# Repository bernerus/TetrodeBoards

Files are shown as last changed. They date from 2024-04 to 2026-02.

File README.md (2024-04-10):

# TetrodeBoards
The Tetrode Boards by Ian White, GM3SEK. Redesigned with KiCad.

In 1998 Ian White, G3SEK, nowadays GM3SEK designed control and protection circuits for RF power amplifiers
that use tube tetrodes. These boards were sold for many years by the designer but were retired around 2017
and are no longer available.

The manuals are still available however, and that documantation is excellent. 

After my retirement as a system developer I found time to return to the VHF DXing that I used to do as a 
student in the late 1970's.
By then one of the things I built was a VHF power amplifier, described by Fred Merry, W2GN, which was used
even for some EME contacts until around 1987 when a storm took my antenna. Since then, the amplifier was
only used occasionally.

Now, 37 years later, the ham world has changed quite a lot. Nowadays computers make the waveforms and almost
every ham has a spectrum analyzer built into their radio. My signals from the old PA didn't look very good there.

Actually it is probaly at miracle that the PA and its power supply worked at all now. There were lots of electrolytic
capacitors in the power supply that were surplus already in the mid 1970's, and when I got reports on hum on my
signal, I checked these caps. I had only about 8 uF left and the G1 and G2 voltage varied too much to be happy with.

That's when I found out that these tetrode boards could help, but since the boards were no longer sold, I decided
to try to re-engineer them using KiCad. This time using methods available today. Thus this design uses SMD mounted
components and professionally produced boards. I have some boards left, so anyone who likes to try building on these
boards can have them for the expense of postage. Beware though that they have issues. Check the issues tab at GitHub first.

A crucial component in Ian's design is the 748 op amp. 
These are no longer manufactured, but they are available at eBay.
Luckily for me, I found a few 748 IC:s leftover from the happy '70s in my old junkbox. 

Christer Bernérus, SM6FBQ. 
JO67BQ 2024-04-04.

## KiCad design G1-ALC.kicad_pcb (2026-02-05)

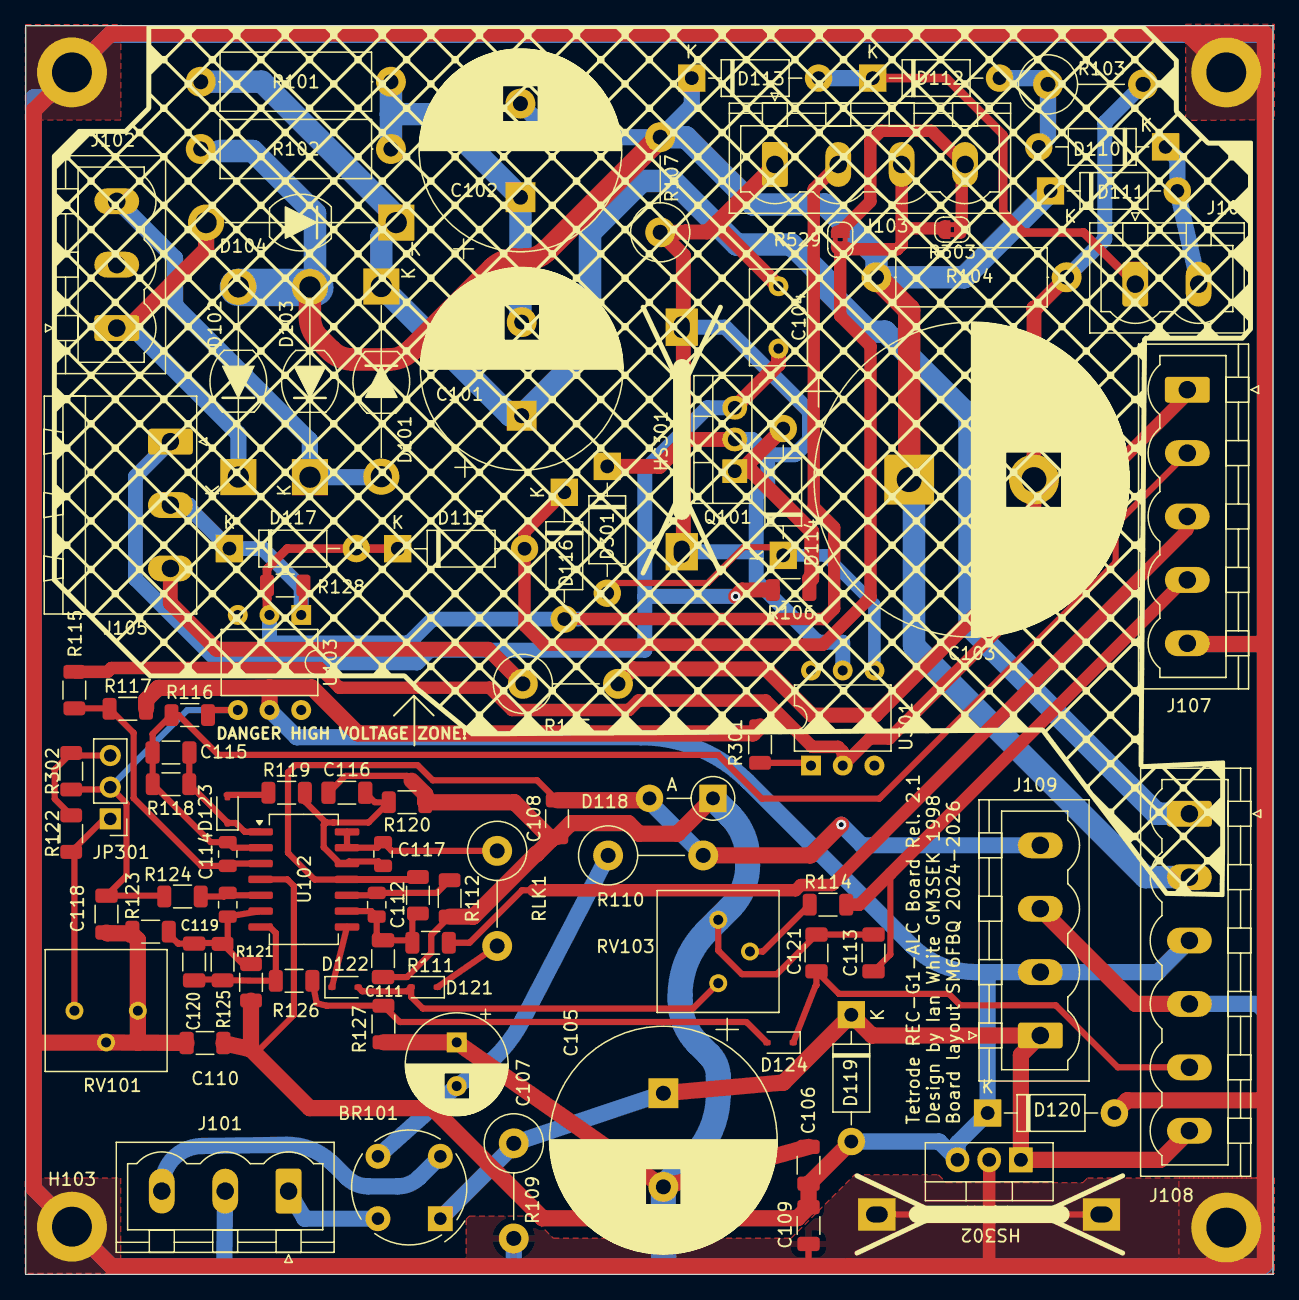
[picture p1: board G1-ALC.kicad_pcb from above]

Board: 2 copper layers, 100.0 x 100.1 mm, 96 parts (0 on the bottom side), 49 nets.

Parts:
BR101: 2W06; Diode_Bridge_Round_D9.0mm
C101, C102: 100u 350V; CP_Radial_D16.0mm_P7.50mm
C103: 220u 200V; CP_Radial_D25.0mm_P10.00mm_SnapIn
C104: 100n 100V; C_Disc_D7.5mm_W4.4mm_P5.00mm
C105: 4m7 35V; CP_Radial_D18.0mm_P7.50mm
C106, C108, C109, C110, C111, C113, C115, C118, C120, C121: 100n; C_1206_3216Metric
C107: 100u 35V; CP_Radial_D8.0mm_P3.50mm
C112, C114, C117, C119: 33p; C_0805_2012Metric
C116: 1u; C_1206_3216Metric
D101, D102, D103, D104: BY228; D_SOD-64_P15.24mm_big_holes_Horizontal
D110, D111, D112, D113, D115, D116, D117, D119, D120: 1N4007; D_DO-41_SOD81_P10.16mm_Horizontal
D114: BZX85C56; D_DO-41_SOD81_P10.16mm_Horizontal
D118: BZX55C12V; D_DO-41_SOD81_P5.08mm_Vertical_AnodeUp
D121, D122, D123, D124: 1N4148WS; D_SOD-323
D301: 1N5365 36V; D_DO-41_SOD81_P10.16mm_Horizontal
H101, H102, H103, H104: MountingHole_Pad; MountingHole_3.2mm_M3_DIN965_Pad
HS301, HS302: Heatsink_Pad_2Pin; 6025DG_Cooler
J101: Conn_01x03_Pin; PhoenixContact_MSTBVA_2,5_3-G-5,08_1x03_P5.08mm_Vertical
J102: 330VAC; PhoenixContact_MSTBVA_2,5_3-G-5,08_1x03_P5.08mm_Vertical
J103, J109: G1 conn.; PhoenixContact_MSTBVA_2,5_4-G-5,08_1x04_P5.08mm_Vertical
J104: 105VAC in; PhoenixContact_MSTBVA_2,5_2-G-5,08_1x02_P5.08mm_Vertical
J105: Conn_01x03_Pin; PhoenixContact_MSTBA_2,5_3-G-5,08_1x03_P5.08mm_Horizontal
J107: Conn_01x05_Pin; PhoenixContact_MSTBVA_2,5_5-G-5,08_1x05_P5.08mm_Vertical
J108: G2 Control board interconnect; PhoenixContact_MSTBVA_2,5_6-G-5,08_1x06_P5.08mm_Vertical
JP301: ALC tune; PinHeader_1x03_P2.54mm_Vertical
Q101: TIP122; TO-220-3_Vertical
R101, R102, R104: 100k 2W; R_Axial_DIN0414_L11.9mm_D4.5mm_P15.24mm_Horizontal
R103: 1k5 2W; R_Axial_DIN0414_L11.9mm_D4.5mm_P7.62mm_Vertical
R105: 3k3 2W; R_Axial_DIN0414_L11.9mm_D4.5mm_P7.62mm_Vertical
R106, R122: 470R; R_1206_3216Metric
R107, R109: 4k7 2W; R_Axial_DIN0414_L11.9mm_D4.5mm_P7.62mm_Vertical
R110: 470R 1W; R_Axial_DIN0414_L11.9mm_D4.5mm_P7.62mm_Vertical
R111, R112, R115, R116, R121, R124: 10k; R_1206_3216Metric
R113: 100k; R_1206_3216Metric
R114: 100R; R_1206_3216Metric
R117, R118, R125: 470k; R_1206_3216Metric
R119: 2k7; R_1206_3216Metric
R120: 1M; R_1206_3216Metric
R123, R128: 22k; R_1206_3216Metric
R126: 39k; R_1206_3216Metric
R127: 33k; R_1206_3216Metric
R301: 270R; R_1206_3216Metric
R302: 560R; R_1206_3216Metric
R303, R529: 0; SolderJumper-2_P1.3mm_Bridged2Bar_RoundedPad1.0x1.5mm
RLK1: 0R; R_Axial_DIN0414_L11.9mm_D4.5mm_P7.62mm_Vertical
RV101: 1k; Potentiometer_Bourns_3386P_Vertical
RV103: 10k; Potentiometer_Bourns_3386P_Vertical
U101: LM7812_TO220; TO-220-3_Vertical
U102: LM324; SO-14_5.3x10.2mm_P1.27mm
U103: MCT5211M; DIP-6_W7.62mm
U301: CNY17-4; DIP-6_W7.62mm

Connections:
+12V: C106.1, C109.1, C110.1, D119.2 (A), D120.1 (K), J108.3, J109.2, R117.2, R121.2, R301.1, U101.3 (VO), U102.4 (V+), U103.5
+24V Unreg: BR101.1 (+), C105.1, D119.1 (K), J108.6, J109.1, R109.1, U101.1 (VI)
-12V: C108.2, D118.2 (A), J109.4, R110.2, R113.1, U102.11 (V-)
/18 VAC +: BR101.4, J101.1
/18 VAC -: BR101.2, J101.3
/105 VAC +: D112.1 (K), D113.2 (A), J104.1
/105 VAC -: D110.1 (K), D111.2 (A), J104.2
/330VAC +: D102.1 (K), D104.2 (A), J102.1
/330VAC -: D101.2 (A), D103.1 (K), J102.3
/ALC: C113.1, J107.4, R114.2
/Cathode: C102.2, C103.1, D102.2 (A), D103.2 (A), D111.1 (K), D113.1 (K), J108.2, R102.2, R104.1, R107.2
/Class AB1_L: J107.1, R115.1, U301.2
/G1: J103.4, R303.1, R529.1
/G1 Switch: C104.1, D301.1 (K), HS301.1, HS301.2, J103.1, Q101.2 (C), R107.1, U301.5
/G1 meter +: D115.1 (K), D116.2 (A), D117.2 (A), J103.2, R128.1, U103.2
/G1 meter -: D115.2 (A), D116.1 (K), J103.3, R303.2, R529.2
/G1 trip: C121.2, D124.1 (K), J108.5
/G2 Unreg: C101.1, D101.1 (K), D104.1 (K), J108.1, R101.1
/Ig1: C114.2, C115.1, J107.2, R116.1, R118.1, U102.2 (-)
/Inhibit: J107.3, R111.1
/RV102 Cold: C104.2, J105.1, Q101.3 (E), R106.2
/RV102 Hot: J105.3, R105.1
/RV102 Mid: D117.1 (K), J105.2, R128.2, U103.1
GND: C105.2, C106.2, C107.1, C108.1, C109.2, C110.2, C111.2, C113.2, C116.1, C118.2, C121.1, D118.1 (K), D120.2 (A), H101.1, H102.1, H103.1, H104.1, HS302.1, HS302.2, J101.2, J107.5, J108.4, J109.3, R109.2, R112.2, R120.1, R123.1, R127.1, RV101.2, RV101.3, RV103.3, U101.2 (GND)
unnamed: BR101.3 (-), C107.2, R110.1
unnamed: C101.2, C102.1, R101.2, R102.1
unnamed: C103.2, R103.2, R104.2, R105.2
unnamed: C120.2, R125.2, R126.1, U102.7
unnamed: D110.2 (A), D112.2 (A), R103.1
unnamed: D114.2 (A), Q101.1 (B), R106.1
unnamed: D114.1 (K), D301.2 (A), U301.4
unnamed: D121.2 (A), D122.2 (A), RV103.1
unnamed: D121.1 (K), RLK1.2
unnamed: D122.1 (K), U102.8
unnamed: D123.2 (A), R119.1
unnamed: C115.2, D123.1 (K), R118.2, U102.1
unnamed: D124.2 (A), R126.2, R127.2
unnamed: JP301.1 (A), R122.2, RV101.1
unnamed: JP301.3 (B), R122.1, R302.2
unnamed: C118.1, JP301.2 (C), R116.2, R124.1, R302.1, U103.4
unnamed: R114.1, RV103.2
unnamed: R301.2, U301.1
unnamed: C114.1, R115.2, R117.1, U102.3 (+)
unnamed: C119.1, R124.2, U102.5 (+)
unnamed: C119.2, C120.1, R121.1, R123.2, R125.1, U102.6 (-)
unnamed: C112.1, R112.1, U102.10 (+)
unnamed: C111.1, C112.2, R111.2, R113.2, U102.9 (-)
unnamed: C116.2, C117.1, R119.2, R120.2, U102.12 (+)
unnamed: C117.2, RLK1.1, U102.13 (-), U102.14

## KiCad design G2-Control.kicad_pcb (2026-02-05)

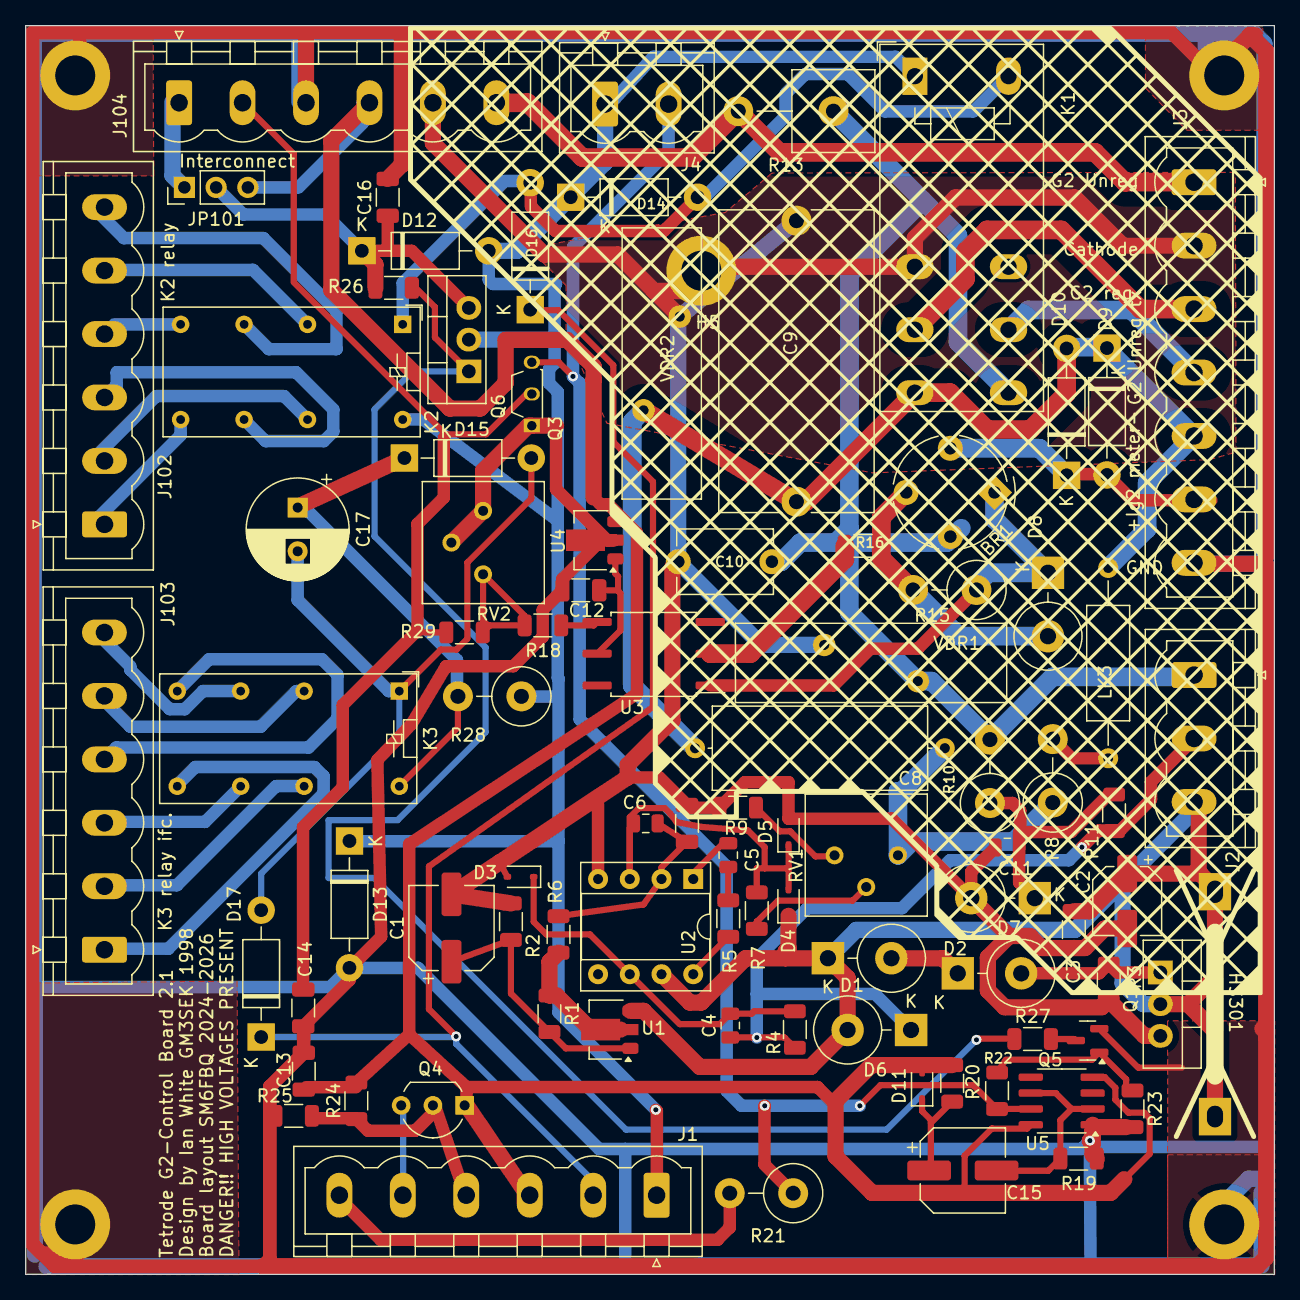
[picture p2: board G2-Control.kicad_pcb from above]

Board: 2 copper layers, 100.0 x 100.0 mm, 93 parts (0 on the bottom side), 61 nets.

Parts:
BR1: 2W06; Diode_Bridge_Round_D9.0mm
C1, C15: 100u 16V; CP_Elec_6.3x5.7
C2: 10u 50V; CP_Elec_5x5.4
C3, C7, C13, C14, C16: 100n; C_1206_3216Metric
C4: 10n; C_0805_2012Metric
C5, C6: 33p; C_0805_2012Metric
C8: 4n7 630V; C_Axial_L17.0mm_D6.5mm_P20.00mm_Horizontal
C9: 100n 1kV; C_Rect_L24.0mm_W12.2mm_P22.50mm_MKT
C10: 10n 1kV; C_Disc_D7.5mm_W5.0mm_P7.50mm
C11: 470n; C_0805_2012Metric
C12: 10u; C_1206_3216Metric
C17: 100u 50V*; CP_Radial_D8.0mm_P3.50mm
D1, D2: BZX55C15V; D_DO-201_P5.08mm_Vertical_KathodeUp
D3, D4, D5, D11: 1N4148WS; D_SOD-323
D6: BZX55C12V; D_DO-201_P5.08mm_Vertical_KathodeUp
D7: BZT03C82; D_DO-201_P5.08mm_Vertical_KathodeUp
D8: 1N5337B; D_DO-201_P5.08mm_Vertical_KathodeUp
D9, D10, D12, D13, D14, D15, D16, D17: 1N4007; D_DO-41_SOD81_P10.16mm_Horizontal
H1, H2, H3, H4, H5: MountingHole_Pad; MountingHole_3.2mm_M3_DIN965_Pad
HS301: Heatsink_Pad_2Pin; 6025DG_Cooler
J1, J102, J103: Conn_01x06_Pin; PhoenixContact_MSTBVA_2,5_6-G-5,08_1x06_P5.08mm_Vertical
J2: Q2_link; PhoenixContact_MSTBVA_2,5_3-G-5,08_1x03_P5.08mm_Vertical
J3: Conn_01x07_Pin; PhoenixContact_MSTBVA_2,5_7-G-5,08_1x07_P5.08mm_Vertical
J4: Conn_01x05_Pin; PhoenixContact_MSTBVA_2,5_2-G-5,08_1x02_P5.08mm_Vertical
J104: Board Interconnect; PhoenixContact_MSTBVA_2,5_6-G-5,08_1x06_P5.08mm_Vertical
JP101: Relay voltage; PinHeader_1x03_P2.54mm_Vertical
K1: Schrack RTE24024; Relay_DPDT_Schrack-RT2-FormC_RM5mm
K2, K3: AZ822-2C-24DSE; Relay_DPDT_Omron_G5V-2
LK3: Jumper_2_Bridged; R_Axial_DIN0309_L9.0mm_D3.2mm_P15.24mm_Horizontal
Q1: TIP122; TO-220-3_Vertical
Q3: 2N5061; TO-92S_Wide
Q4: 2N4403; TO-92_Inline_Wide
Q5: BC847; SOT-23
Q6: IRF9530N; TO-220-3_Vertical
R1: 270R; R_1206_3216Metric
R2: 4k7; R_1206_3216Metric
R3: 470R; R_1206_3216Metric
R4: 39k; R_1206_3216Metric
R5: 2k7; R_1206_3216Metric
R6, R7: 22k; R_1206_3216Metric
R8: 470k 1W; R_Axial_DIN0414_L11.9mm_D4.5mm_P5.08mm_Vertical
R9: 27k*; R_1206_3216Metric
R10: 150k 1W*; R_Axial_DIN0414_L11.9mm_D4.5mm_P5.08mm_Vertical
R11: 82k; R_1206_3216Metric
R13: 10k 2W*; R_Axial_Power_L20.0mm_W6.4mm_P7.62mm_Vertical
R15: 120R 1W*; R_Axial_DIN0414_L11.9mm_D4.5mm_P5.08mm_Vertical
R16: 820R*; R_1206_3216Metric
R18: 220R; R_1206_3216Metric
R19: 330k*; R_1206_3216Metric
R20: 100k; R_1206_3216Metric
R21: 470R 1W; R_Axial_DIN0414_L11.9mm_D4.5mm_P5.08mm_Vertical
R22, R23, R24, R25, R26, R27, R29: 10k; R_1206_3216Metric
R28: 680 1W*; R_Axial_DIN0414_L11.9mm_D4.5mm_P5.08mm_Vertical
RV1: 10k; Potentiometer_Bourns_3386P_Vertical
RV2: 500R; Potentiometer_Bourns_3386P_Vertical
U1: LM317L_SOT89; SOT-89-3
U2: uA748; DIP-8_W7.62mm_Socket
U3: 4N36; SOP-6_6.62x6.62mm_P2.54mm
U4: 78L05; SOT-89-3
U5: LMC555CMX; SOIC-8_3.9x4.9mm_P1.27mm
VDR1, VDR2: V320LA40B*; RV_Disc_D21.5mm_W6.1mm_P7.5mm

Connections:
+5V: C12.1, U3.5, U4.1 (OUT)
+12V: C13.1, D11.2 (A), J1.3, J104.4, JP101.3 (B), Q4.1 (E), R20.2, R24.2, U4.3 (IN), U5.4 (R), U5.8 (VCC)
/24V Unreg: J104.1, JP101.1 (A)
/+30V rail: C2.1, C3.1, D1.1 (K), D4.1 (K), D6.2 (A), HS301.1, HS301.2, J2.3, Q1.2 (C), U1.3 (VI), U2.7 (V+)
/+Ig2: BR1.2, D9.2 (A), D10.1 (K), J3.6
/-Ig2: C8.2, C9.1, D9.1 (K), D10.2 (A), J3.5, K1.14, LK3.2 (B), VDR2.1
/AUX_TRIP_L: J4.2, Q3.3 (A), R21.1, R22.1, U5.7 (DIS)
/Alarm LED +: J1.5, Q4.3 (C)
/Alarm LED -: J1.6, R21.2
/CATHODE: C1.2, C2.2, C3.2, C7.2, C9.2, C10.2, C11.2, D3.2 (A), D5.2 (A), D7.2 (A), H5.1, J3.2, J104.5, K1.12, Q1.3 (E), R2.1, R3.1, R9.1, U2.4 (V-), VDR1.2, VDR2.2
/G1 trip: C14.1, J104.2, Q3.2 (G), R29.2
/G2 UNREG TX: J3.4, K1.21
/G2 Unreg: J3.1, J104.6, R13.2
/G2 reg: J3.3, K1.11
/HV Enable: D12.2 (A), D13.1 (K), D14.1 (K), J1.1, J4.1, K1.A1, K2.16, Q6.2 (D), R28.1
/K2B_NC: J102.6, K2.6
/K2B_NO: J102.4, K2.8
/K2B_com: J102.5, K2.4
/K2C_NC: J102.3, K2.11
/K2C_NO: J102.1, K2.9
/K2C_com: J102.2, K2.13
/K3B_NC: J103.6, K3.6
/K3B_NO: J103.4, K3.8
/K3B_com: J103.5, K3.4
/K3C_NC: J103.3, K3.11
/K3C_NO: J103.1, K3.9
/K3C_com: J103.2, K3.13
/PTT_L: D16.1 (K), D17.1 (K), J1.2
/Q2G: C4.1, D6.1 (K), J2.2, R4.2, R11.1
/R12: BR1.4, C10.1, J2.1, K1.24, R10.2, R13.1, VDR1.1
/Reset -: J1.4, Q4.2 (B), R24.1, R25.2
GND: C12.2, C13.2, C14.2, C16.2, D13.2 (A), H1.1, H2.1, H3.1, H4.1, J3.7, J104.3, Q3.1 (K), Q5.2 (E), R19.2, R23.2, R25.1, RV2.1, RV2.2, U4.2 (GND), U5.1 (GND)
unnamed: BR1.1 (+), D8.1 (K), R15.1, U3.1
unnamed: BR1.3 (-), D8.2 (A), R15.2, R16.2
unnamed: C5.1, R5.1
unnamed: C5.2, U2.1 (NULL)
unnamed: C8.1, R8.1, RV1.3
unnamed: D1.2 (A), D2.1 (K)
unnamed: D2.2 (A), Q1.1 (B), R3.2
unnamed: C4.2, D3.1 (K), R4.1, U2.6
unnamed: C6.1, D4.2 (A), D5.1 (K), R7.2, U2.3 (+)
unnamed: C11.1, D7.1 (K), R10.1, R11.2
unnamed: C15.1, D11.1 (K), R20.1
unnamed: C16.1, D12.1 (K), JP101.2 (C), Q6.3 (S), R26.1
unnamed: D14.2 (A), D16.2 (A), K1.A2, K2.1
unnamed: C17.2, D15.2 (A), D17.2 (A), K3.1
unnamed: C17.1, D15.1 (K), K3.16, R28.2
unnamed: LK3.1 (A), R8.2
unnamed: Q5.1 (B), R22.2, R23.1
unnamed: Q5.3 (C), R27.2
unnamed: Q6.1 (G), R26.2, R27.1
unnamed: R7.1, RV1.2
unnamed: R9.2, RV1.1
unnamed: R16.1, U3.2
unnamed: R18.1, R29.1, RV2.3
unnamed: R18.2, U3.4
unnamed: C1.1, R1.2, R2.2, U1.1 (ADJ)
unnamed: R1.1, R6.1, U1.2 (VO)
unnamed: C6.2, C7.1, R6.2, U2.2 (-)
unnamed: R5.2, U2.8 (FC)
unnamed: C15.2, R19.1, U5.2 (TR), U5.6 (THR)

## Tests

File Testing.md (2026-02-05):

# Testing and initial power up.

These are the testing steps I went through when powering up the boards the very first time.
If any test failed, I went back, documented the issue, produced a workaround or a fix and
updated the design to make the next release better.

## Low voltage DC power up.

### Transformer checks

In the following, I used two transformers, one for the low voltages and one for the higher voltages.
Hence, I'm talking about different transformers. If you have only one, after the identification and testing, be sure to keep the
high voltage windings isolated until they are actually being used.

#### Primary connection

Measure the primary winding. There may be many connections.
Find the pair of connections that have the largest resistance.
Connect these, in a safe way, to the mains voltage. You should hear a very soft hum
from the transformer. If it makes more noise that a soft hum, you might have connected
to the wrong winding or a pair of connections to the primary winding that was not designed
for your mains voltage.

Now let the transformer run on mains voltage without connecting anything to the secondary winding(s).
Observe it for 10 minutes, then disconnect it from mains, and feel it with your hands. It should not feel warm anywhere.
If it gets noisy, oe warm, or if you see smoke or you feel any smell from it, disconnect immediately. The primary test has failed.

#### Secondary winding check.

Now turn to the secondary winding. It should deliver at least 2x16V with a mid tap.
Identify the mid tap by measuring the voltage between the different connections. Find one pair that gives 32-48 Volts. These are
the outer connections. The mid tap is the third one. Check that the voltage between the mid tap and the outer connections is between
16 avd 19 V and absolutely no more than 24V. When done, disconnect tre transformer from the mains.

### G1-ALC Low voltage check

Connect the secondary winding connections to J101 of the G!-ALC board.with the mid tap
to the middle pole of J101. Turn the transformer on.

Check that the DC voltage between ground and pin 6 of J108 (closest to the corner) is 22-27V
Check that the DC voltage between ground and pin 3 of J108 and pin 2 of J109 is 11.8-12.3V
Check that the DC voltage between ground and pin 4 of J109 is about -12V.

Let the voltage be on for a few minutes and check that nothing is getting warm.

### G2-Control low voltage check

Turn off the transformer.

Make connections between J108 on the G1-ALC board to J104.
The pin order is order same on both boards, but mirrored,  so you could use a flat band of wires.

Verify the connection between J108 on the G1-ALC board to J104 by measuring the resistance from, JP101, pin closest to the corner on the G2 board,
to J108 pin 6, (closest to the corner) i.e. the middle of the board edge. It should be 0-0.2 ohms.

Unplug any jumper on JP101

Turn the transformer on again.
Check that the DC voltage on the pin closest to the corner of J104 is 22-27V
Check that the DC voltage on the 4:th pin from the corner of J104 is 11.8-12.3V
Check that the DC voltage on pin 1 of U4 is 5V.

Turn the transformer off

Re-plug any unplugged jumper on JP101

### G2-Control G2 rectifier low voltage check

Connect the low voltage transformer secondary to J102 on the G1-ALC board instead of J101.
Turn the transformer on

Check the DC voltage between CATHODE and G2-unreg pins of J108.
(These are the two pins of J108 closest to J104) You should see about 44-52 Volts, depending on the transformer.
Note that this is just a check using low voltages, in the final setup the voltage should be considerablu higher.

Turn the transformer off

## G1 voltage power up

### Transformer check

Apply mains power to the primary winding. Measure the voltages on the secondary windings,
Find out which winding gives about 100 VAC, and which gives more than 300VAC.
Disconnect the transformer from mains.

### Check voltages of the G1 section

Connect the low voltage transformer secondary to J101 on the G1-ALC board. J102 should be unconneced.
Connect the secondary 100 VAC winding to J104. Leave the 300VAC winding unconnected and isolated.
Smoke test. If something smells warm or smoke erupts, turn off both transformers immediately

#### Wire up a PTT button.
Connect a PTT button between J1 pin2 (PTT_L) and J3 pin 7 (GNDPWR) On the G2-control board.

#### Configure for G1 switching

If R107 is a resistor and not a link:
Connect a link between J102 pin 5 and J103 pin 5 on the G2-control board.
Connect a wire between J103 pin 4 and J3 pin 4 on the G2-control board. (CATHODE)
Connect a wire between J102 pin 4 on the G2-control and J103 pin 1 (G1 Switch) on the G1-ALC board.
Apply mains power to the low voltage transformer
Check with an ohmmeter that there is no connection between J103 pin 1 (G1 Switch) on the G1-ALC board
and J3 pin 4 on the G2-control board. When pushing the PTT switch, the relays should click and the
ohmmeter should read near 0 ohms. 

Release the button and the connection should disappear.

Disconnect mains power from the low voltage transformer

#### Wire up a switch for Class select
Get an SPST swich. Set the switch to open.
On the G1-ALC board, Connect it between J107 pin 1 (CLASS AB1_L, On version 2.0.0 boards erroneously marked G2 Unreg) 
and 5 (GND, On 2.0.0 boards erroneously marked G1 current trip).

#### Test G1 output voltages

Apply power to the low voltage transformer.

Connect both transformers to mains voltage.
Beware, there are now lethal voltages available on the boards.
Check that the DC voltage on the 4:th pin from the corner of J104 to ground is 11.8-12.3V
Check the G1 out voltage against the CATHODE rail (J108 pin 2), should be less than -100V.
Press the PTT button. The voltage should rise to about -93 to -92 Volts depending on the position of RV102.
Release the button.

Flip the SPST switch to the ON (Class AB1) position.
The voltage should be between -84 to -81V depending on the position of RV102
With the PTT button pressed, the voltage should rise to about between -50 to -56V V
Check that there is about 12V on J107 pin 1 against ground.

Disconnect mains power from the transformers

## G2 voltage check and adjustment

##### Check 30V Rail

Now, with the transformers off, connect the 100 VAC winding ( NO, not the 330V yet) to J102 on the G1-ALC board.
Connect the voltmeter between pin 4 and 7 of yet empty socket of U2. Positive on pin 7.
Turn on the transformers. The voltmeter should show +30V approximately. If not, fix before continuing. The 748 is precious!!
Turn the transformers off again.

##### Install the 748

Now it's time to put in the 748 in its socket. IMPORTANT! Do not continue without it or you will burn R13 due to VDR1 clamping the overvoltage produced without the 748 regulating it down below 400V.
Observe the polarity of the 748.

##### Connect the 330 volt winding

**WARNING EVEN MORE LETHAL VOLTAGES WILL BE PRESENT DURING THESE TESTS**

Disconnect the 100V Winding from J102 and put it back into J101.
Connect the 330V winding to J102 instead.

##### Test and measure the unregulated G2 voltage

Connect the voltmeter negative end to the CATHODE rail (J108-2 on G1 board)
Connect the voltmeter positive end to the G2-UNREG output (J108-1 on the G1 board)
Turn the transformer on briefly, the voltmeter should show between 350 to 400V.
If voltages seems OK, turn on for 10 seconds and then off.
Look and smell for smoke and heat building up. DO NOT TOUCH ANYTHING until the voltmeter goes below 30V.

Turn the transformers off.

##### Test the warm up timing

Wait for about 10 minutes before proceeding to allow the warmup timing capacitor to leed out all its charge. Get a stopwatch ready while waiting.
Turn the transformers again and start the stopwatch. The LED should be fully lit.
After about 2 or 3 minutes the LED should go almost off. Then stop the watch.
Check the required warmup time needed for your tube(s). You may want to adjust the value of R20 to get the desired time.
Remember that each time you thurn the transformer on, you will have to wait this time before trying to enable the G2 voltage.

##### Measure and adjust the G2 regulated voltage output

Now move the positive probe to the G2 Reg output (J3 pin 3)
Adjust RV102 to its middle position.
Turn the transformers on again.
Voltmeter should show 0 V because the relay connects to the CATHODE rail.
Push the PTT Button, the relays should click and the voltmeter should show over 300V.
Adjust RV101 while pushing the PTT switch until the voltmeter shows 350V (For 4CX250B)
Release the PTT switch and turn the transformers off.

##### Check waveform of G2

Connect an oscilloscope in parallel to the voltmeter. Use a 10x probe. Check that the waveform when pushing the PTT button
is absolutely flat. If not, the transformer may need more turns of wire for the G2 winding.

##### Adjust the G2 trip current.

Turn RV2 fully clockwise.
Compute what resistance is needed to load the trip current needed. I needed to load 40 mA and at 350V I needed a resistance of 8750 ohms at 14W.
Connect the load resistance between the G2 output pin and the cathode pin.
Connect the voltmeter to measure the current through the load resistance and fine adjust the resistance,
while pressing the PTT button until the current is at the computed trip current (40 mA in my case)
When you have the precise load resistance needed,
push the PTT button and very slowly turn RV2 counterclockwise until the LED lights up and the relays drop.
Press the reset button and the LED should go dark again.
disconnect the meter and leave the load current path open, Push the PTT button again and the LED should stay dark.

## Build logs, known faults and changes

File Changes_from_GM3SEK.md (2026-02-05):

I have made a few changes from Ian's original design.

# G2 rectifier

The original schematic shows four 1N4007 forming a rectifier bridge.
However, the original board layout shows that each leg of the
rectifier is supposed to use two 1N4007 in series.

Maybe things have changes the last 30 years, but then the usual way of
extending the voltage handling capability for a diode was to
put diodes in series and have bleeder resistances of equal values
parallelling the diodes to make sure that they split the back voltages
in equal parts. Also each diode should have a capacitor across to protect against
voltage surges. I couldn't see any place for resistors or capacitors on the photos
I have seen on the internet, I decided instead to use another diode, the BY220 which is
good for 3 A and 1200V. These are also avalanche diodes which means that they can
be put in series without any extra components. If you need more than one in series
for higher voltage, put one in each hole vertically and tie them together on top.
Dont forget to change the filter caps in that case.

# 24V Relays

I happened to have five PCB relays **with another pinout** than the ones Ian used, and they were
for 24V. I  changed the circuit to allow to feed unregulated 24V to the relays instead of 12V.
There is a jumper on the G2 board to select this.
This means two things:

1. Ian's description for wiring for G1 switching is not correct using my boards. The relay pinout differs.
2. The K3 relay has a capacitor and a series resistor to make it slow. From the original documentation,
   I reverse engineered the time-on and time-off delay to be ~330 mS and ~600 mS respectively.
   If another relay is used than the relay specified by Ian, the component values for R29 and C17
   will most likely to be recalculated. I used a 24V relay that needed >14V to turn on and <10V to turn off,
   and the coil resistance measured to 2900 ohms. Feeding this with 24V, I got 1800 ohms for R28 and 330 uF 25V
   for C17 to get about the same timing.

# Connectors

I like to be able to easily take out boards for inspection, repair or testing new ideas.
All connections have been taken to the edge of the board, or at least close to the edge.
There is space for Phoenix PCB connectors with 5.08 mm spacing.
There are matching female screw connectors for these and they are certified up to 500V.
Unfortunately they are a bit pricey.

# SMD components

I wanted to make a professional PCB. I have previously ordered PCB's from Elecrow who offer
PCBs for only $1 for 5 boards if the size is max 100x100 mm, so I wanted to keep the size down.
That's why I decided to use SMD components where possible. Mounting them may feel as a
challenge, but I also ordered a stencil for each board cost me another $10 but worth it.
The challenge is mostly to keep track on all components and putting them in place on the
solder paste. A hot air gun and the solder mask together with the surface tension of liquid
does the final adjustment.
The boards are two layer, plated through holes, tinned copper, solder mask and silkscreen print on both sides.
When ordering from Elecrow you always get 5 boards, but it is not uncommon that you get more, so I
have 10 empty boards left for anyone interested. I might lend you the stencils.

# Class C

Since '98 ham radio has evolved. Nowadays there is a lot of machine generated modes, most notably FT8.
Many of these modes employ a constant amplitude, this means that PA's in Class C are interesting again.
As an experiment I included some circuitry to make it possible to switch the bias voltage
between 2 different values. This circuit uses an optocoupler to short-circuit one zener diode
of two that makes up the bias reference.

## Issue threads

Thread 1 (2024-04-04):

Missing traces on the G1-ALC board

bernerus, 2024-04-04:
There are two missing traces on the G1-ALC board.
This was due to me not running the electrical design checker on the schematic and a grid mismatch.

The negative ends of C102 and R102 are not connected. They should both be connected to the CATHODE rail.

As for the capacitor, I just bent the negative lead towards the cathode of D113 and soldered it there on the rear side of the board.

As for R102 I bent the unconnected lead, the one closest to J102,  onto the anode end of D103 snd soldered it there, also on the rear side.

See also:
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

bernerus, 2024-04-13:
The missing traces has been added in release 2.0.0

Closed 2024-04-07.

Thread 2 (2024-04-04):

Too small holes for the BY228 diodes on the G1-ALC board.

bernerus, 2024-04-04:
To save space I replaced the double 1N4007 diodes on Ian's boards with
the more sturdy avalanche diodes BY228 which is good for 1200V and 3A.

However these diodes are so sturdy that they come
with 1.35 mm leads. I knew this but somehow in the process, the change in hole size got lost,
so to be able to fit the BY228 diodes, I first cut the leads to the approximate needed length.
Then mounted each end in a drill and while slowly turning the diode with the drill
I used a Dremel round sanding band at medium speed to sand down the other
end lead diameter to about 1mm (or until fitting the hole) for a length of approximately 3 mm.
This reveals its copper core but that only matters until it is soldered in place.

bernerus, 2024-04-13:
Board release 2.0.0 has larger holes.

Closed 2024-04-07.

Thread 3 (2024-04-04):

Connectors turned the wrong way

bernerus, 2024-04-04:
The silkscreen graphics in many places show the curly end turned outwards.
Don't mount them like this, turn the curly end inwards, otherwise the screws
will be turned inwards making it harder to measure voltages on the screws.

The silkscreen text showing what signal is connected to each pin still applies,
but pin numbering does not.

This issue applies to both boards.

The attached picture shows a screw connector inserted in a socket having the curls inwards.
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

bernerus, 2024-04-13:
The board release 2.0.0 has the graphics turned the right way. Note that pin numbering may be changed from r1.0.0

Closed 2024-04-07.

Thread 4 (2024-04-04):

G1-ALC board. Heat sink too close to capacitor

bernerus, 2024-04-04:
The heat sink that is cooling Q101 is too close to capacitor C101.
There is room enough for the heat sink itself but not really for the screw
that bonds to the transistor.
This causes the heatsink to lean over to C103 which doesn't look nice,
and the only way to mount the heatsink is to first screw Q101 together with
the heat sink and then solder the transistor, or alternatively to mount
C103 after mounting the heat sink.

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

bernerus, 2024-04-13:
Board release 2.0.0 has more space for the heat sink and also copper on top to facilitate soldering of the heat sink onto the board.

Closed 2024-04-07.

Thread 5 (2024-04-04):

G2-Control board:  U1 connected backwards

bernerus, 2024-04-04:
This is by far the worst issue. The LM317 voltage stabilizer U1 was turned the wrong way on the schematic compared to Ian's original.  Usually signals go from left to right in a schematic, and that's what I assumed, however in this case VIN is to the right
and VOUT to the left.
The electrical rules checker of course warned about this but I didn't run it. :-(

The consequence is that this error has of course migrated to the physical board, and U1 is here a SMD component so the fix requires surgery that connect the pads of R1 and R2 being closest to each other to be isolated from U1 pin 3 and instead
be connected ti U1 pin 2. Likewise the 30V rail that starts at U2 pin 7 snd that makes a clockwise loop around R4 and must be isolated from U1 pin 2 and instead be connected to pin 3.

I made a cut in the 30V rail track about 3 mm from U1 pin 2, and scraped the copper clean on about 1mm along the other side of the cut, i.e. the side still connected to U2 pin 7. Tinned the free copper and soldered a tinned piece of cutaway resistor lead between U1 pin 3 and the tinned copper.

On the other side of U1 I cut  track leading to pin 3 immediately at the edge of U1 and soldered a cutaway resistor lead between  the pad of R1 that is connected to R2, to the rear side of U1 pin 2.

See this picture.
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

bernerus, 2024-04-13:
The board release 2.0.0 has this issue fixed.

Closed 2024-04-07.

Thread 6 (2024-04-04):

G2-Control board: Awkwardly turned Q1

bernerus, 2024-04-04:
Q1 on the G2-Control board is turned such that the heat sink is facing to the inward of the board. Then it comes very close to
the capacitor C2. It should be turned the other way round so that the heat sink could be soldered directly to the grounded edge of the board, provided that Q1 is mounted isolated from the heat sink.

bernerus, 2024-04-13:
Board release 2.0.0 has Q1 the other way around.

Closed 2024-04-07.

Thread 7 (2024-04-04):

D6 can reside on the G2-Control board

bernerus, 2024-04-04:
The zener diode D6 was excluded from the G2-control board because it was drawn in the breakout box together with Q2 and R12.
However both nets it is connecting to are also available on the board, thus it can be placed there somewhere, simplifying the
off-board circuitry.

bernerus, 2024-04-13:
Woarkaround for boards Release 1.0.0 is tho mount the diode with the cathode end onto thr outer enf of R4 and the anode end onto the cathode end of D1. The first point should be connected to the middle pin of J2, and the second to the pin closest to Q1 of J2
on the original first batch of boards. Of course it can be mounted on the backside of the board directly on the J2 pins, but maybe you want the back side clean of components.

bernerus, 2024-04-13:
Board release 2.0.0 has D6 incorporated.

Closed 2024-04-07.

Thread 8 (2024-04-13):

J107 and J108 should change places on the G1-ALC Board

bernerus, 2024-04-13:
J108 is the interconnect receptacle for the G2-controö board. It would look better
if J108 changed place with J107 because then the interconnect would line up
with the interconnect on the G2-Control board,

bernerus, 2024-04-13:
This was easier than I thought. However it expanded the high voltage zone, but the new layout has that zone clearly printed.

bernerus, 2024-04-13:
The board release 2.0.0 has the connectors swapped. This changes the external interface, which requires a major release numbewr bump.

Closed 2024-04-13.

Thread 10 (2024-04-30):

R26 must connect to the source of Q6.

bernerus, 2024-04-30:
In the original schematic, I connected the hot end of R26 to +12V. This does not work when using 24V feed to the relays.
To make it work, the hot end of R26 must be connected directly to the source of Q6.

bernerus, 2024-05-05:
The schematic and the PCB has been changed accordingly.

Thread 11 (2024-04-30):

Q4 turned backwards

bernerus, 2024-04-30:
The silkscreen print turns Q4 backwards. This was actually caused by selecting wrong schematic symbol which numbered the pins in the wrong direction for the 2N4403. The workaround for the initial board is just to mount Q4 the other way round, i.e. against
what the silkscreen print show.

Closed 2024-05-05.

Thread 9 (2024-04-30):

Q6 connected backwards.

bernerus, 2024-04-30:
The MOSFET Q6 that controls the T/R Relay was originally turned upside down in the schematic.
This caused the Drain and Source pins to be interchanged on the original PCB.
Due to the pinout of the IRF9530 this cannot be fixed by mounting the transistor reversed.

bernerus, 2024-05-05:
I did work around this. It was a bit tricky.
There are two trace cuts to make:
1: On the reverse side, cut the connection to the Q6 pin closest to J104 right where the trace leaves the pin.
2. On the top side, cut the trace leading from the cathode end of D12 to the middle pin of Q6.

Then there are two patches to add:
A: On the reverse side, connect a wire from the cathode pin of D12 to the Q6 pin closest to J104.
B: Also on the reverse side, connect a wire fron the anode pin of D12 to the middle pin of Q6.

On the first picture, there is a red wire leading to the cathode of D12. This wire does not have anything to do with this issue.
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
[](url)
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

bernerus, 2024-05-05:
Second picture shows the patches on the reverse side.

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

bernerus, 2024-05-05:
The symbol has been turned correctly in the schematic and the PCB traces have been updated.

Closed 2024-05-05.

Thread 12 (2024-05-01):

Warmup time and R20

bernerus, 2024-05-01:
The warmup time with the default seems to be 2 minutes.
That's a long time and lot all tubes need to have that long time to warm up.
To shorten the warmup time, decrease the value of R20.

bernerus, 2024-05-05:
Changed the value of R20 from 100k to 100k* to mark as something that might need adjustment. Different tubes needs different warmup time.

Closed 2024-05-05.

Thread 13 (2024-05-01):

G2 trip current too high

bernerus, 2024-05-01:
I wanted the G2 trip current to be 30 mA. That could not be achieved, It turned out that the value of R16 (1k5) was too high and caused the optocoupler to only deliver a few milliamps at 30 mA IG2. Changing R15 from 82R to 120R did not help.
I put another 1k5 in parallell which made it possible to set the 30 mA limit somewhere in the middle range of  RV2. In the next version I will change R16 to 820R.

bernerus, 2024-05-05:
R16 changed to 820R* (* to mark as something that might need adjustments) in the schematic. No change to the PCB.

Closed 2024-05-05.

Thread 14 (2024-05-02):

Wrong value for R128

bernerus, 2024-05-02:
The value for R128 should be 22k, not 1k5 as it is in the initial release.

bernerus, 2024-05-05:
My workaround was to desolder R128 and soldering in a THT resistor directly between pins 1 and 2 on U103.

The value of R128 has been updated in the schematic. There is no change to the PCB. Just use the correct value.

Closed 2024-05-05.

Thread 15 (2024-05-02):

R123  Missing

bernerus, 2024-05-02:
R123 is missing from the initial schematic. Consequently also on the initial PCB.

bernerus, 2024-05-05:
With the initial board, the workaround is to add a THT resistor according to attached picture. I did not find a 22k resistor small enough. The resistor I used is 23k.
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

bernerus, 2024-05-05:
R123 has been added to the schematic and the PCB in version 2.0.0.

Closed 2024-05-05.

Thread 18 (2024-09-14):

Pads for R106 on the G1-ALC board is  missing

bernerus, 2024-09-14:
The soldering pads for R106, 470 Ohms, is missing.
The resistor can however easily be soldered on the backside of the bard between Q101-3 and D114-2.

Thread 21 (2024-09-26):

100k too high a value for R126

bernerus, 2024-09-26:
The SCR did not react to G1 current too high. I could see that U102 was delivering +12V, but still
the SCR did not fire. Measuring the voltage at the cathode of D124 showed only 0.719V. The SCR needs 0.8 V to trigger.
Experimentally I found that 56k worked in version  1.0, but in version 2, I needed to go to 39k to establish good functionality.
There seems to be quite some spreading of component values. Maybe we need even lower values.

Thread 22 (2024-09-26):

ALC troubleshooting

bernerus, 2024-09-26:
The manual from GM3SEK states in chapter 9.5 step 8 that it might be necessary to either
short-circuit R122 (under the board) or change its value to 1k.
This procedure becomes quite awkward to do as these components are here surface mounted.
For version 2.1 I added a 560 ohm resistor in series with R122 and a 3 way jumper to be able to achieve
all 3 options here. See the notes page of the schematic.

Disbarred, 2025-06-10:
Happy to find this group.  Been tinkering with my 4cx30a HF Tetrode Board project since 2020.
How can I learn about the newer SMT boards?
Neil, n2eye, NY City

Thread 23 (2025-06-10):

Interested in new version of Tetrode Boards w/ SMT components

Disbarred, 2025-06-10:
I have been building (seems to never stop, lol) my Tetrode Boards HF amp since 2020  (2x 4cx300a).  I certainly want to keep this project alive and available for the Amateur Radio community.  Where can I learn more about and/or obtain a set of the newer boards?
Neil, NY City, n2eye
antclacorp@aol.,com

bernerus, 2025-06-12:
Hello Neil.

Well, I haven't published anything about this yet because I wanted to complete my rebuild of the PA power supply which contains the tetrode boards. While not fully done that – I want to integrate some remote control and telemetry – I can now see that the tetrode boards at least guards against G2 current runaway, but maybe it is too good. One thing that seems to have been forgotten by G3SEK is the bleed current caused by resistors at the tube sockets. This current is constant and positive, and it does not go into the screen grids of the tube, but the tetrode boards still sense it and maybe triggers the safety mechanism too early. I will think through this during the summer. Another thing is the Class C option  that I built into the new boards. As it it implemented now it only affects the G1 bias, and that seems to work. However in the class C case more G1 current should probably be allowed. This is something that also needs to be tested, as well as whether the G! voltage regulation works as it should.

Yet another thing is the use of the 748. These chips hasn't been produced for decades. I happened to have just a few lying around from the 1970's so that's what I used. They can be found on eBay though, but if this project is going to survive, maybe another circuit needs to be found.

I'll have to check in the latest version of my design, the version I have tested. The kiCad sources and gerbers will be updated here at GitHub.

I used the Chinese company Elecrow to produce the boards. They make them in small quantities  for 1 USD if the size is max 100x100 mm.
A stencil for the SMD pads cost 5 USD. Freight to Sweden is about 8 USD, and no tariffs as far as I can see.

Disbarred, 2025-06-18:
Thank you. n2eye

Sent from the all new AOL app for iOS

On Thursday, June 12, 2025, 6:38 AM, Christer Bernérus ***@***.***> wrote:

bernerus left a comment (bernerus/TetrodeBoards#23)
Hello Neil.

Well, I haven't published anything about this yet because I wanted to complete my rebuild of the PA power supply which contains the tetrode boards. While not fully done that – I want to integrate some remote control and telemetry – I can now see that the tetrode boards at least guards against G2 current runaway, but maybe it is too good. One thing that seems to have been forgotten by G3SEK is the bleed current caused by resistors at the tube sockets. This current is constant and positive, and it does not go into the screen grids of the tube, but the tetrode boards still sense it and maybe triggers the safety mechanism too early. I will think through this during the summer. Another thing is the Class C option that I built into the new boards. As it it implemented now it only affects the G1 bias, and that seems to work. However in the class C case more G1 current should probably be allowed. This is something that also needs to be tested, as well as whether the G! voltage regulation works as it should.

Yet another thing is the use of the 748. These chips hasn't been produced for decades. I happened to have just a few lying around from the 1970's so that's what I used. They can be found on eBay though, but if this project is going to survive, maybe another circuit needs to be found.

I'll have to check in the latest version of my design, the version I have tested. The kiCad sources and gerbers will be updated here at GitHub.

I used the Chinese company Elecrow to produce the boards. They make them in small quantities for 1 USD if the size is max 100x100 mm.
A stencil for the SMD pads cost 5 USD. Freight to Sweden is about 8 USD, and no tariffs as far as I can see.

—
Reply to this email directly, view it on GitHub, or unsubscribe.
You are receiving this because you authored the thread.Message ID: ***@***.***>

Disbarred, 2025-06-29:
Thank you.Especially for the info about how to order another board set.  I think the circuit is awesome including the manual.  I’m rebuilding my setup (again) had a bang a few months ago and took opportunity to rebuild tube deck.  Neil, nyc 

Sent from the all new AOL app for iOS

On Thursday, June 12, 2025, 6:38 AM, Christer Bernérus ***@***.***> wrote:

bernerus left a comment (bernerus/TetrodeBoards#23)
Hello Neil.

Well, I haven't published anything about this yet because I wanted to complete my rebuild of the PA power supply which contains the tetrode boards. While not fully done that – I want to integrate some remote control and telemetry – I can now see that the tetrode boards at least guards against G2 current runaway, but maybe it is too good. One thing that seems to have been forgotten by G3SEK is the bleed current caused by resistors at the tube sockets. This current is constant and positive, and it does not go into the screen grids of the tube, but the tetrode boards still sense it and maybe triggers the safety mechanism too early. I will think through this during the summer. Another thing is the Class C option that I built into the new boards. As it it implemented now it only affects the G1 bias, and that seems to work. However in the class C case more G1 current should probably be allowed. This is something that also needs to be tested, as well as whether the G! voltage regulation works as it should.

Yet another thing is the use of the 748. These chips hasn't been produced for decades. I happened to have just a few lying around from the 1970's so that's what I used. They can be found on eBay though, but if this project is going to survive, maybe another circuit needs to be found.

I'll have to check in the latest version of my design, the version I have tested. The kiCad sources and gerbers will be updated here at GitHub.

I used the Chinese company Elecrow to produce the boards. They make them in small quantities for 1 USD if the size is max 100x100 mm.
A stencil for the SMD pads cost 5 USD. Freight to Sweden is about 8 USD, and no tariffs as far as I can see.

—
Reply to this email directly, view it on GitHub, or unsubscribe.
You are receiving this because you authored the thread.Message ID: ***@***.***>

Disbarred, 2025-08-10:
Speaking of the 748 in DIP-8 form, I just replaced mine with a NOS Fairchild metal can type TO5-8 by soldering it into a DIP-8 socket. The  cans leads divided equally 4 on each side and fit well into the PCB socket.  Soon I'll see if it works.  I've had problems with traces cracking where the TO-220 parts with heatsinks get moved by my clumsy hands.  Soon it will be operating agon.  Thanks for your time.  I'm willing to order another set if you learn of someone ordering another production run.  neil N2EYE

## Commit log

2024-04-04 Initial commit.
    This is the initial commit putting my Kicad design for the tetrode boards
    oroginally desigend by Ian White GM3SEK in 1998.
    This commit reflects the first version that was actually realized physically in 2024.
    Maybe more versions will come, maybe not.
    [G1-ALC-B_Cu.gbr, G1-ALC-B_Mask.gbr, G1-ALC-B_Paste.gbr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]
2024-04-07 Fixes for issuees #1, €2 and #3
    Fixed unconnected capacitor and bleeder
    Turned connectors around to orient screw connectors with screws outward from the board.
    Use new footprint for BY228 diodes with larget pand and holes.
    Added a subsheet for notes containing differences with original drawing from GM3SEK.
    [G1-ALC.kicad_sch, notes.kicad_sch]
2024-04-07 Fixes for issues #1, #2, #3 and #4
    Moved components to make more room for the Q101 heat sink.
    Cleared the top copper layer below the Q101 heat sink forn connected traces.
    Added a copper zone below the Q101 heat sink to make it possible to solder the heat sink onto the board.
    Opened the solder mask below the heat sink.
    Added danger zones on both silkscreen layers. Along with warning texts.
    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
    [G1-ALC.kicad_pcb]
2024-04-07 Added release number to the top silkscreen text.
    [G1-ALC.kicad_pcb]
2024-04-07 Fixes for issues #7 #6 #3 #5
    Connected U1 correctly.
    Added D6 to the board
    Added version number to silkscreen text.
    Added high voltage warning
    Turned Q1 around and moved it closer to the edge.
    [G2-Control.kicad_pcb, G2-Control.kicad_sch]
2024-04-07 Umpdated notes subschematic.
    [notes.kicad_sch]
2024-04-14 Added a mounting hole below VDR2 and copper zones around to get a good grounding point for CATHODE when using the board for cathode grounded PA's. This is suggested in G3SEK's writeup "Power and Prot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
    [G2-Control.kicad_pcb]
2024-04-14 Fix typos and update instructions in Testing.md
    A spelling mistake in the secondary winding section got corrected. Instructions for making connections between J108 on the G1-ALC board and J104 got clarified, including resistance check guidance. Added newly extended steps for G2-Control G2 rectifier low voltage check.
2024-04-14 Update connector positions and routing in G1-ALC.kicad_pcb
    Repositioned two Phoenix Contact connectors in the PCB layout and rerouted the associated traces accordingly. Additionally rotated some properties at F.Fab layer to -90 degrees from the previous posi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
    [G1-ALC.kicad_pcb]
2024-04-14 Add new wiring and mounting hole to G2-Control schematic
    Introduced a mounting hole to the G2-Control KiCad. The hole is
    to be used as a low impedance connection between the CATHODE rail and chassis ground, in case of a cathode grounded PA.
    Otherwise the connection should be connected to the high tension negative pole.
    [G2-Control.kicad_sch]
2024-04-14 Update active layer and adjust circuit properties
2024-04-14 Added copper zones around the new CATHODE low impedance connection.
    [G2-Control.kicad_pcb]
2024-04-14 Add DRC exclusions to G2-Control.kicad_pro
    Added numerous DRC exclusions to the G2-Control.kicad_pro file. Most of the added exclusions address the 'silk_over_copper' issue, limiting potential errors and collisions. Keeping these exclusions recorded is beneficial for maintaining the overall quality.
2024-04-16 Cleaned up the G2-Control schematic.
    Removed Netclass names from their flags and greyed the flags so thet they
    interfere less with the actual schematic.
    Moved things around to avoid collisions.
    Moved D6 into the on-board space and shrunk the cutout for R12 and Q2
    Moved BR1 to get less parallel wirings for the same signal.
    Changed the SCR symbol in the library to make it more clear.
    Shortened the gate pin of Q2 to free some vertical space.
    Changed the values of some components that need to be configured to have an asterisk instead of a default value.
    [G2-Control.kicad_sch]
2024-04-16 Update component properties and positioning in PCB layout
    Several updates were made to the properties and positions of various components in the PCB layout file due to changes in the schematic.
    The Value property for numerous elements was changed, appending an asterisk at the end.
    Additionally, the Reference positions, Datasheet, and Description fields were modified for certain components.
    [G2-Control.kicad_pcb]
2024-04-16 Update DRC exclusions in PCB files
    The list of DRC exclusions was updated due to changes in rules and design checks. Furthermore, the precise placement of elements on nets was altered to match the updated layout.
2024-05-04 Refine testing instructions and update component recommendations
    Significant modifications have been made to the testing instructions in 'Testing.md' for better understanding and accuracy. Additionally, changes in 'Changes_from_GM3SEK.md' included updated recommen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
2024-05-04 Updated junction positions and wire connections in schematic
    Performed major modifications to the junction positions and wire connections in the kicad schematic G1-ALC. The changes include removal and addition of certain junction points, repositioning of wires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
    [G1-ALC.kicad_pcb, G1-ALC.kicad_sch]
2024-05-04 Replaced Q4 transistor schematic symbol BC557 with 2N3904 in G2-Control schematic
    Updated the G2-Control schematic by replacing the schematic symbol BC557 for transistor Q4 with the symbol for 2N3904 which has the same pin numbering as the actual transistor used. This change fixes
    issue #11 and makes the silkscreen print on the PCB show the transistor the way it has to be rotated in order to function properly.
    Other changes is that the references and values of the components have been moved and the valye is set in a smaller font to increase readability. The global labels has also been replaced by hierarchical labels.
    [G2-Control.kicad_pcb, G2-Control.kicad_sch]
2024-05-04 The outputs of the comparators needed pullup resistors. Which have been added. This makes the ERV checker happier.
    [Sequencer.kicad_sch]
2024-05-04 Changed optocoupler U103 to a MCT5211
    The optocoupler U103 must be as sensitive as the MCT5211. It could not be replaced by CNY17-4 despite what is said by Mouser when searching for the MCT5211. Fortunately DigiKey has a direct replacement with the same specifications: MCT5211M.
    [G1-ALC.kicad_pcb, G1-ALC.kicad_sch]
2024-05-05 Cleanup schematic. No functional change.
    Replaced global labels with hierarchical.
    Consistent placement of references and values.
    Values typed in a smaller font.
    [G1-ALC.kicad_pcb, G1-ALC.kicad_sch]
2024-05-05 Moved cold end of R115 to CLASS_AB1_L instead of GND. The intent is to turn off ALC in case we want to run the PA in class C.
    [G1-ALC.kicad_pcb, G1-ALC.kicad_sch]
2024-05-06 Updated relay components and adjusted wiring
    The K1 relay has been updated from model AZ822-2C-24DSE to RTE24024 for better current handling in case of arc-over. Additionally, wiring for these components has been adjusted to fit the new model.
    Moved R13 to a better location and increased its footprint.
    Moved the grounding hole to a place near both the VDR2 and the connection to K1 in order to get as low as possible impedance to the cathode connection for these two components.
    [G2-Control.kicad_sch]
2024-05-06 Updated PCB layout to accommodate new relay model and reworked wiring
    Swapped existing Relay model with the Schrack-RT2 model, and updated PCB layout to accommodate the new output routes. Additionally, repositioned the Resistor R13 to ensure optimal grounding. This change aims at achieving lower impedance for the VDR2 and K1 connections to the cathode.
    [G2-Control.kicad_pcb]
2024-05-06 Update DRC exclusions and active layer in PCB design
    Increased the number of DRC exclusions to accommodate new design rules in the G1-ALC.kicad_pro file.
2024-05-06 Updated capacitor C17. With the smaller relay and higher voltage, coil current is much less so 100 uF gives some 300-500 mS delay.
    [G2-Control.kicad_pcb, G2-Control.kicad_sch]
2024-09-14 Update Testing.md
    Update for version 2.0.0 of the boards.
    The connectors J107 and J108 of the G1 board has switched places and changed pin orders so the description from version 1 is no longer valid. More updates to come...
2024-09-23 Update Testing.md
    Fixed G1 switching paragraphs for vesrion 2.0
2026-02-05 Updated format to KiCad 9. Included footprints etc.
    Standardized PCB layers, updated property formatting, and adjusted net assignments. Added some DigiKey, Electrokit, and Mouser component part numbers.
    Reduced font sizes for better readability and incorporated embedded font settings.
    Removed the sequencer from the schematic which wasn't really meant to be there.
    Revised and excluded drc and erc warnings and exclusions.
    Included footprints into the project library that formerly was defined outside of the project.
    [G1-ALC.kicad_pcb, G1-ALC.kicad_sch, G2-Control.kicad_pcb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]
